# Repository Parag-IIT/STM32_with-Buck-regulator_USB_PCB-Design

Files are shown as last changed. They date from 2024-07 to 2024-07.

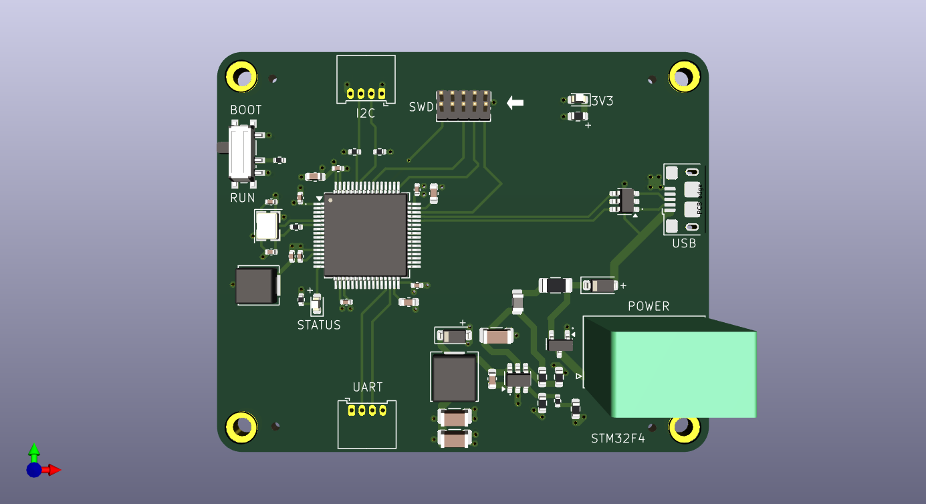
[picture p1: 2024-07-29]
photos/SSTM32_REV2.png

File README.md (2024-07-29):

Sure! Here’s a README.md file for your GitHub repository:

---

# STM32 + USB + Buck Converter PCB Design

Welcome to the STM32 + USB + Buck Converter PCB Design project! This repository contains all the files and documentation for designing a PCB using KiCad that integrates an STM32 microcontroller, a USB interface, and a buck converter.

## Project Overview

This project demonstrates how to create a compact and efficient PCB that combines:
- **STM32 Microcontroller**: Provides robust processing power for a variety of applications.
- **USB Interface**: Enables seamless connectivity for data transfer and device programming.
- **Buck Converter**: Ensures efficient power management and stable performance.

## Applications

This PCB design can be used in various practical applications, including but not limited to:
- USB-Powered Devices
- Data Acquisition Systems
- IoT Gateways
- Smart Home Automation
- Robotics and Automation

## Repository Contents

- `schematics/`: Contains the KiCad schematic files.
- `pcb_layout/`: Contains the KiCad PCB layout files.
- `gerber_files/`: Contains the Gerber files for manufacturing the PCB.
- `bom/`: Bill of Materials listing all components used.
- `docs/`: Additional documentation, including design notes and application examples.
- `images/`: Rendered images of the PCB design.

## Getting Started

### Prerequisites

To work with the files in this repository, you will need:
- [KiCad](https://kicad.org/) (version 6.0 or higher)

### Instructions

1. Open the project in KiCad:
   - Launch KiCad and open the project file located in the `schematics/` directory.
2. Review and modify the schematic:
   - Make any necessary adjustments to the schematic as per your requirements.
3. Generate the netlist:
   - Generate the netlist from the schematic to be used in the PCB layout.
4. Design the PCB layout:
   - Open the PCB layout file in the `pcb_layout/` directory and place the components, route traces, and ensure all design rules are met.
5. Generate Gerber files:
   - Once the PCB layout is complete, generate the Gerber files for manufacturing.

## Usage

### Programming and Debugging

The USB interface allows for easy programming and debugging of the STM32 microcontroller. Connect your development board to a computer via USB and use your preferred IDE (e.g., STM32CubeIDE) to upload and debug your firmware.

### Power Management

The buck converter efficiently steps down the input voltage to a suitable level for the STM32 and other components, ensuring stable and reliable operation.

## Contributing

Contributions are welcome! If you have any ideas, improvements, or bug fixes, please open an issue or submit a pull request.

## Contact

For any questions or further information, feel free to contact me at [parag067@gamil.com].

---

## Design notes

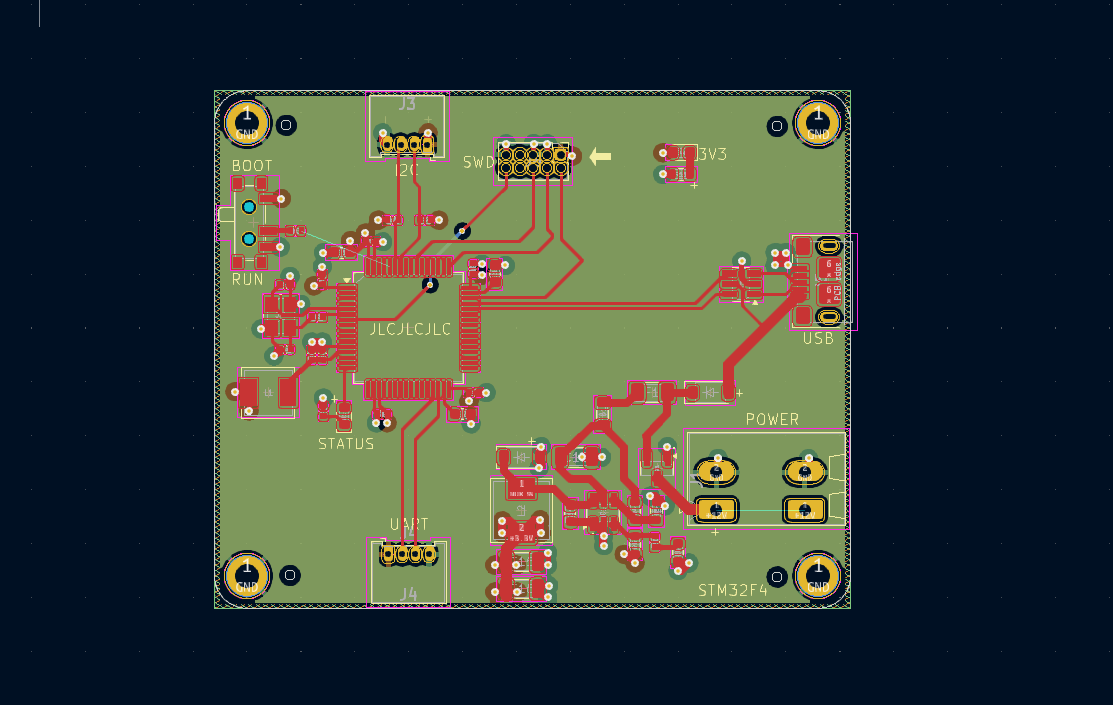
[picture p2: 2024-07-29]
photos/Screenshot 2024-07-29 125918.png

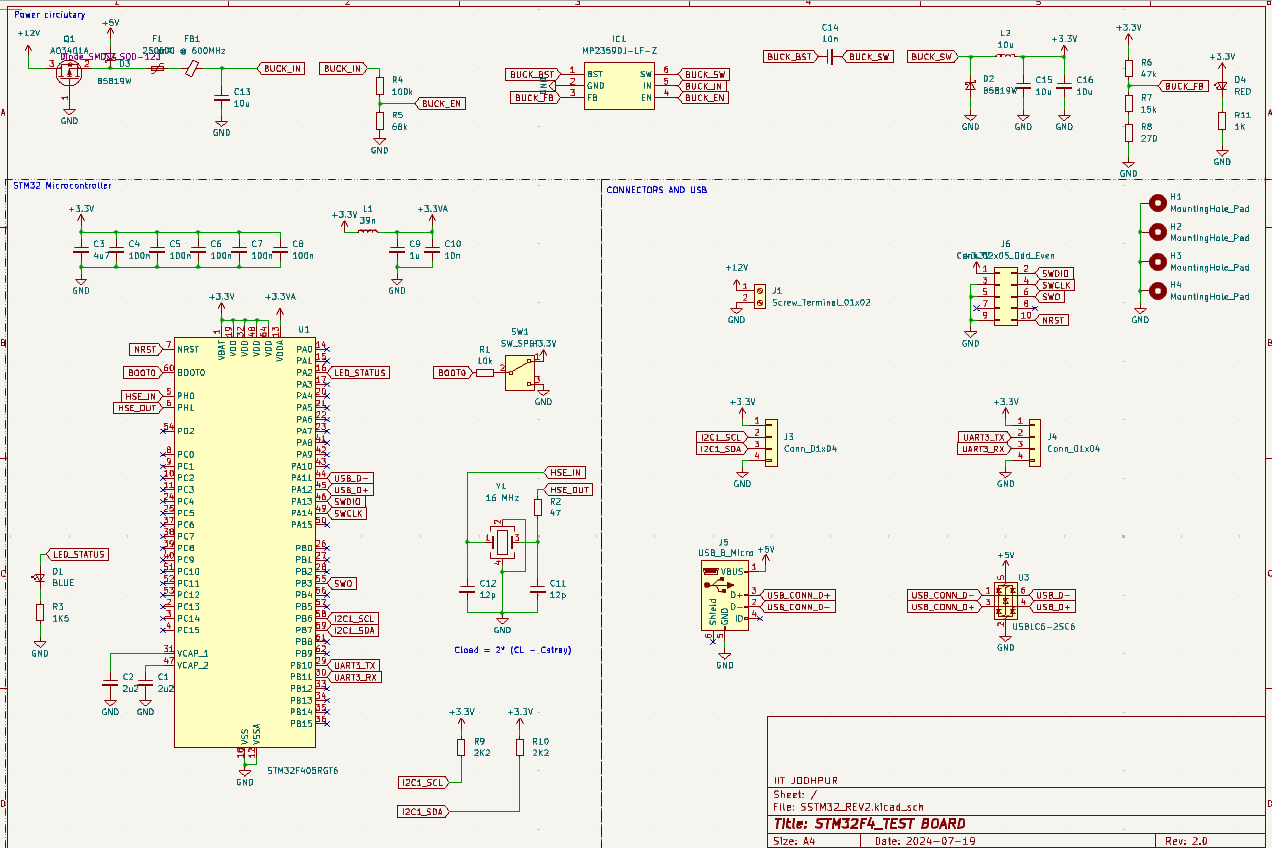
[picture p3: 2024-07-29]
photos/Screenshot 2024-07-29 130210.png

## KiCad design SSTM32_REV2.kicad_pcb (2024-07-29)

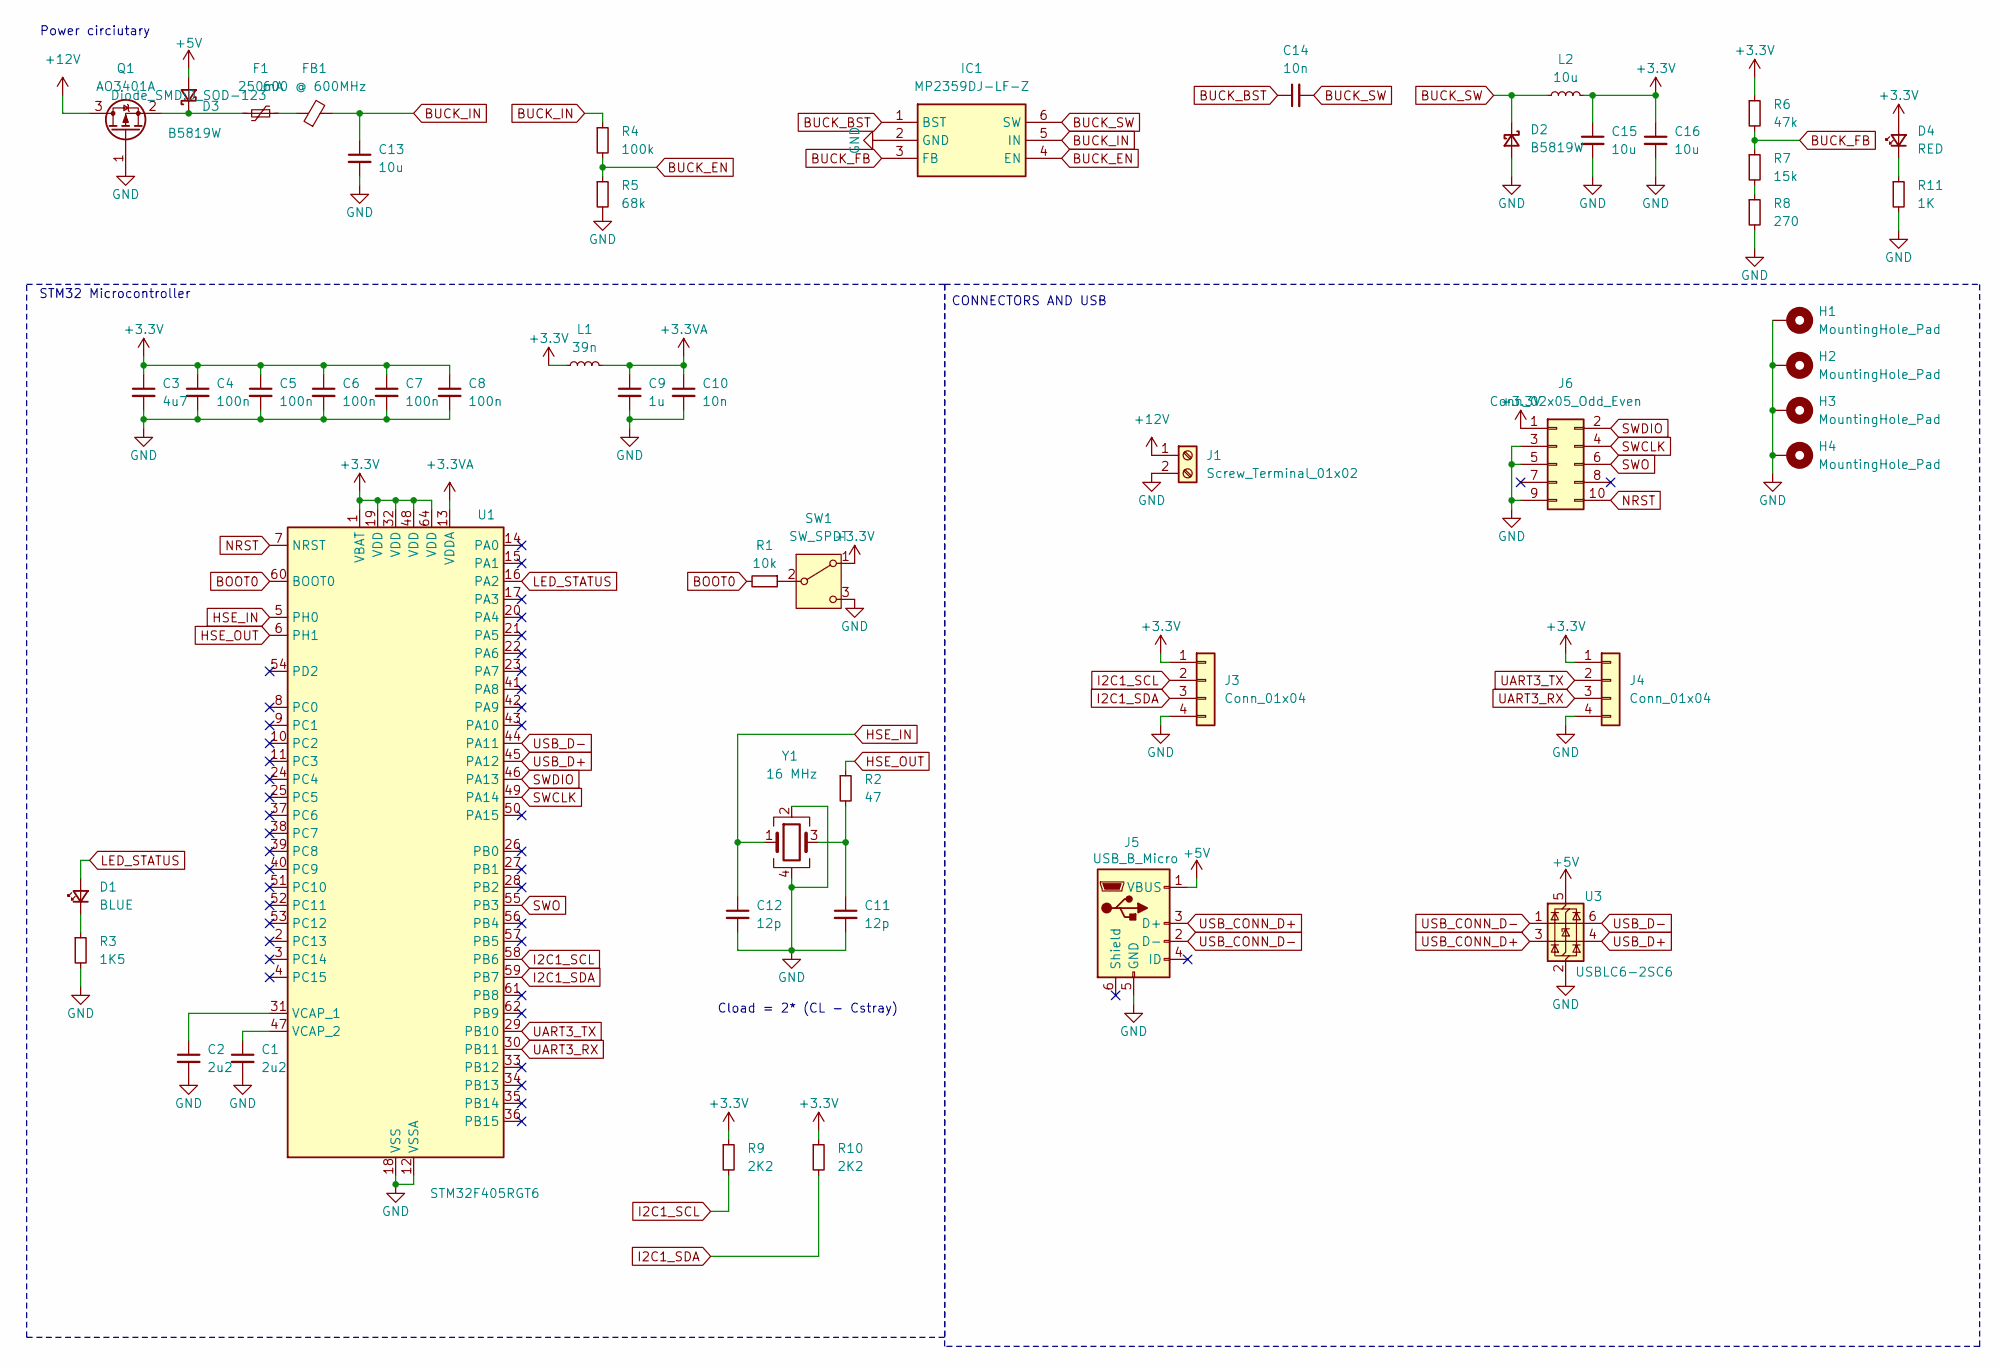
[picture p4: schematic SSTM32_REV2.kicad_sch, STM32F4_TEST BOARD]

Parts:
C1, C2: 2u2; C_0603_1608Metric
C3: 4u7; C_0603_1608Metric
C4, C5, C6, C7, C8: 100n; C_0402_1005Metric
C9: 1u; C_0402_1005Metric
C10: 10n; C_0402_1005Metric
C11, C12: 12p; C_0402_1005Metric
C13, C15, C16: 10u; C_1206_3216Metric
C14: 10n; C_0603_1608Metric
D1: BLUE; LED_0603_1608Metric
D2, D3: B5819W; D_SOD-123
D4: RED; LED_0603_1608Metric
F1: 250mA; Fuse_1206_3216Metric
FB1: 600 @ 600MHz; L_0805_2012Metric
H1, H2, H3, H4: MountingHole_Pad; MountingHole_2.2mm_M2_DIN965_Pad
IC1: MP2359DJ-LF-Z; SOT-23-6; Mouser Part Number 946-MP2359DJLFZ
J1: Screw_Terminal_01x02; PhoenixContact_SPT_1.5_2-H-3.5_1x02_P3.5mm_Horizontal
J3, J4: Conn_01x04; Molex_PicoBlade_53048-0410_1x04_P1.25mm_Horizontal
J5: USB_B_Micro; USB_Micro-B_Amphenol_10118193-0002LF_Horizontal
J6: Conn_02x05_Odd_Even; PinHeader_2x05_P1.27mm_Vertical
L1: 39n; L_Sunlord_MWSA0402S
L2: 10u; L_Sunlord_MWSA0518S
Q1: AO3401A; SOT-23
R1: 10k; R_0402_1005Metric
R2: 47; R_0402_1005Metric
R3: 1K5; R_0402_1005Metric
R4: 100k; R_0603_1608Metric
R5: 68k; R_0603_1608Metric
R6: 47k; R_0603_1608Metric
R7: 15k; R_0402_1005Metric
R8: 270; R_0603_1608Metric
R9, R10: 2K2; R_0402_1005Metric
R11: 1K; R_0603_1608Metric
SW1: SW_SPDT; SW_SPDT_PCM12
U1: STM32F405RGT6; LQFP-64_10x10mm_P0.5mm
U3: USBLC6-2SC6; SOT-23-6
Y1: 16 MHz; Crystal_SMD_3225-4Pin_3.2x2.5mm

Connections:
+3.3V: C3.1, C4.1, C5.1, C6.1, C7.1, C8.1, C15.1, C16.1, D4.2 (A), J3.1, J4.1, J6.1, L1.1, L2.2, R6.1, R9.1, R10.1, SW1.1 (A), U1.1 (VBAT), U1.19 (VDD), U1.32 (VDD), U1.48 (VDD), U1.64 (VDD)
+3.3VA: C9.1, C10.1, L1.2, U1.13 (VDDA)
+5V: D3.2 (A), J5.1 (VBUS), U3.5 (VBUS)
+12V: J1.1, Q1.3 (D)
BOOT0: R1.2, U1.60 (BOOT0)
BUCK_BST: C14.1, IC1.1 (BST)
BUCK_EN: IC1.4 (EN), R4.2, R5.1
BUCK_FB: IC1.3 (FB), R6.2, R7.1
BUCK_IN: C13.1, FB1.2, IC1.5 (IN), R4.1
BUCK_SW: C14.2, D2.1 (K), IC1.6 (SW), L2.1
GND: C1.2, C2.2, C3.2, C4.2, C5.2, C6.2, C7.2, C8.2, C9.2, C10.2, C11.2, C12.2, C13.2, C15.2, C16.2, D2.2 (A), H1.1, H2.1, H3.1, H4.1, IC1.2 (GND), J1.2, J3.4, J4.4, J5.5 (GND), J6.3, J6.5, J6.9, Q1.1 (G), R3.2, R5.2, R8.2, R11.2, SW1.3 (C), U1.12 (VSSA), U1.18 (VSS), U1.63 (VSS), U3.2 (GND), Y1.2, Y1.4
HSE_IN: C12.1, U1.5 (PH0), Y1.1
HSE_OUT: R2.1, U1.6 (PH1)
I2C1_SCL: J3.2, R9.2, U1.58 (PB6)
I2C1_SDA: J3.3, R10.2, U1.59 (PB7)
LED_STATUS: D1.2 (A), U1.16 (PA2)
NRST: J6.10, U1.7 (NRST)
unnamed: C11.1, R2.2, Y1.3
unnamed: D1.1 (K), R3.1
unnamed: D3.1 (K), F1.2, Q1.2 (S)
unnamed: D4.1 (K), R11.1
unnamed: F1.1, FB1.1
unnamed: R7.2, R8.1
unnamed: R1.1, SW1.2 (B)
unnamed: C2.1, U1.31 (VCAP_1)
unnamed: C1.1, U1.47 (VCAP_2)
SWCLK: J6.4, U1.49 (PA14)
SWDIO: J6.2, U1.46 (PA13)
SWO: J6.6, U1.55 (PB3)
UART3_RX: J4.3, U1.30 (PB11)
UART3_TX: J4.2, U1.29 (PB10)
USB_CONN_D+: J5.3 (D+), U3.3 (I/O2)
USB_CONN_D-: J5.2 (D-), U3.1 (I/O1)
USB_D+: U1.45 (PA12), U3.4 (I/O2)
USB_D-: U1.44 (PA11), U3.6 (I/O1)

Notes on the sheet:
CONNECTORS AND USB
Cload = 2* (CL - Cstray)
Power circiutary
STM32 Microcontroller

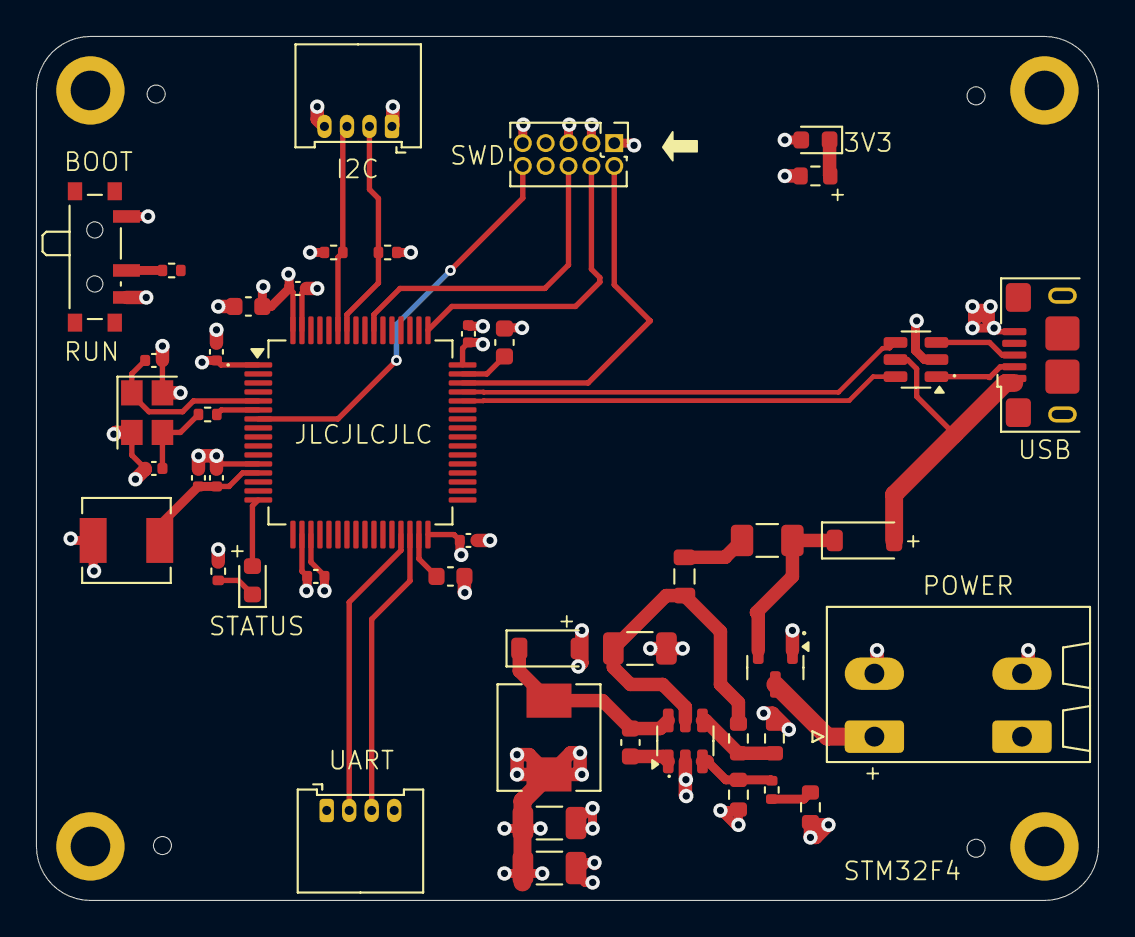
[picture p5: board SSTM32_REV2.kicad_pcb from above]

Board: 4 copper layers, 59.0 x 48.0 mm, 50 parts (0 on the bottom side), 35 nets.
